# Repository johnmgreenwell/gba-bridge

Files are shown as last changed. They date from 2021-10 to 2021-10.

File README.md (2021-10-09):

# GBA Bridge Project

Gameboy Advance cartridge data read/write to/from SD card

## Overview

This AVR ATMega325 microcontroller-based project is capable of extracting ROM and RAM from Gameboy Advance (GBA) cartridges and saving them to an SD card. It is also capable of uploading RAM to a gameboy cartridge from a file on the SD card, allowing transfer of save data from one cartridge to another. Supported RAM types include EEPROM, Flash, FRAM, and SRAM of varying memory sizes.

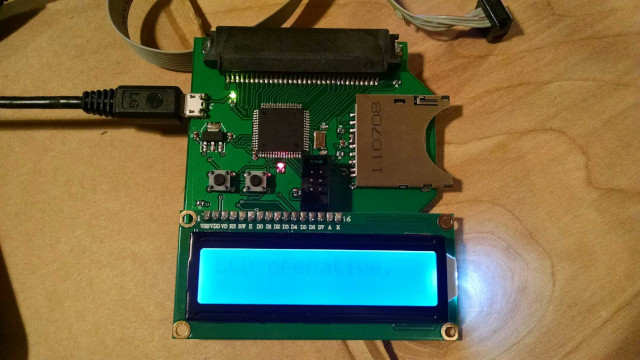
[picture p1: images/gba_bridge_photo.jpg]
Final Build


An simple LCD provides feedback to the user concerning mode and operation, controlled with two simple pushbuttons. The USB micro connection provides power, but does not transmit data. Improvements to this design might omit the SD card and physical UI, and implement the read/write feature entirely by way of USB connection.

Some reverse-engineering of transmission protocol was necessary to successfully communicate with GBA cartridge 8-pin EEPROM chips. This was made possible by tying each pin to a digital oscilloscope while the game was active, and triggering on save/load commands issued within the game.

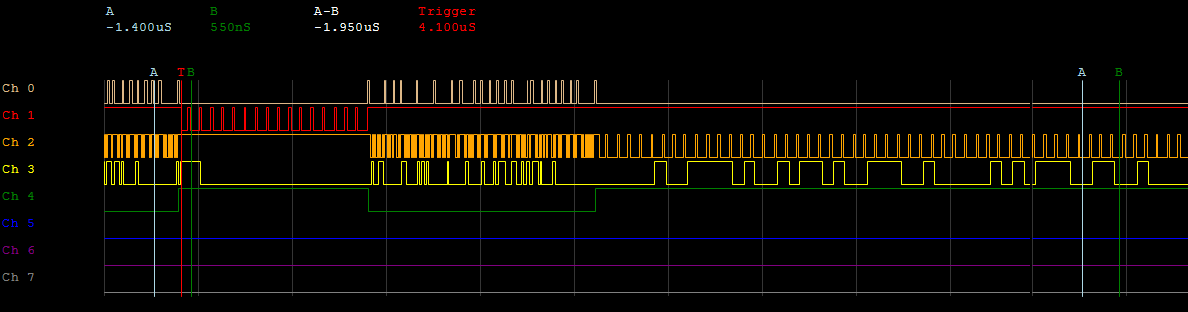
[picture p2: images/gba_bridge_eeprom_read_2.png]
EEPROM Read Example


In the current version, the user must examine the game cartridge internal circuit board to ascertain the type of memory used. Improvements to the code might add functionality which auto-detects RAM type and read/writes as desired.

Data extracted from the GBA cartridge is available as a .sav file on the SD card. To upload a .sav file to the RAM on a GBA cartridge, a file called up.sav containing the data should be placed on the SD card and then the appropriate steps followed in the UI of the board.

## Code

The main project file gba_bridge.c depends on separate header and source files to control peripheral devices, including the GBA cartridge. The collective C code was written and compiled in AVR Visual Studio 6, and the resulting .hex file uploaded to the board using *avrdude* through ICSP. 

The code consists of an extended state machine as a function of user input through the two onboard pushbuttons.

```c
	/* Continual Loop */
	/* This state machine cycles through options indicated */
	/* by user input about course of computation action.   */
	/* State machine states:			*/
	/* 0: Introductory screen			*/
	/* 1: Read from ROM select			*/
	/* 2: Read RAM select EEPROM 8k		*/
	/* 3: Read ROM select 2MB			*/
	/* 4: Read RAM select EEPROM 512	*/
	/* 5: Write RAM select okay			*/
	/* 6: Read ROM select 4MB			*/
	/* 7: Read ROM select 8MB			*/
	/* 8: Read ROM select 16MB			*/
	/* 9: Read ROM select 32MB			*/
	/* 10: Execute Read ROM 2MB			*/
	/* 11: Execute Read ROM 4MB			*/
	/* 12: Execute Read ROM 8MB			*/
	/* 13: Execute Read ROM 16MB		*/
	/* 14: Execute Read ROM 32MB		*/
	/* 15: Read RAM select Flash		*/
	/* 16: Read RAM select F/SRAM		*/
	/* 17: Execute RAM read EEPROM 8k	*/
	/* 18: Execute RAM read	EEPROM 512	*/
	/* 19: Execute RAM write EEPROM 512	*/
	/* 20: Execute RAM read Flash		*/
	/* 21: Execute RAM read F/SRAM		*/
	/* 22: Execute RAM write EEPROM 8k	*/
	/* 23: Execute RAM write Flash		*/
	/* 24: Execute RAM write F/SRAM		*/
	/* 25: Write RAM select EEPROM 512	*/
	/* 26: Write RAM select EEPROM 8k	*/
	/* 27: Write RAM select Flash		*/
	/* 28: Write RAM select F/SRAM		*/
```

## Schematic

The schematic and PCB CAD files as developed in KiCad provide the required components and connections of the design. It may be necessary to compatibility update the older files to newer KiCad format.

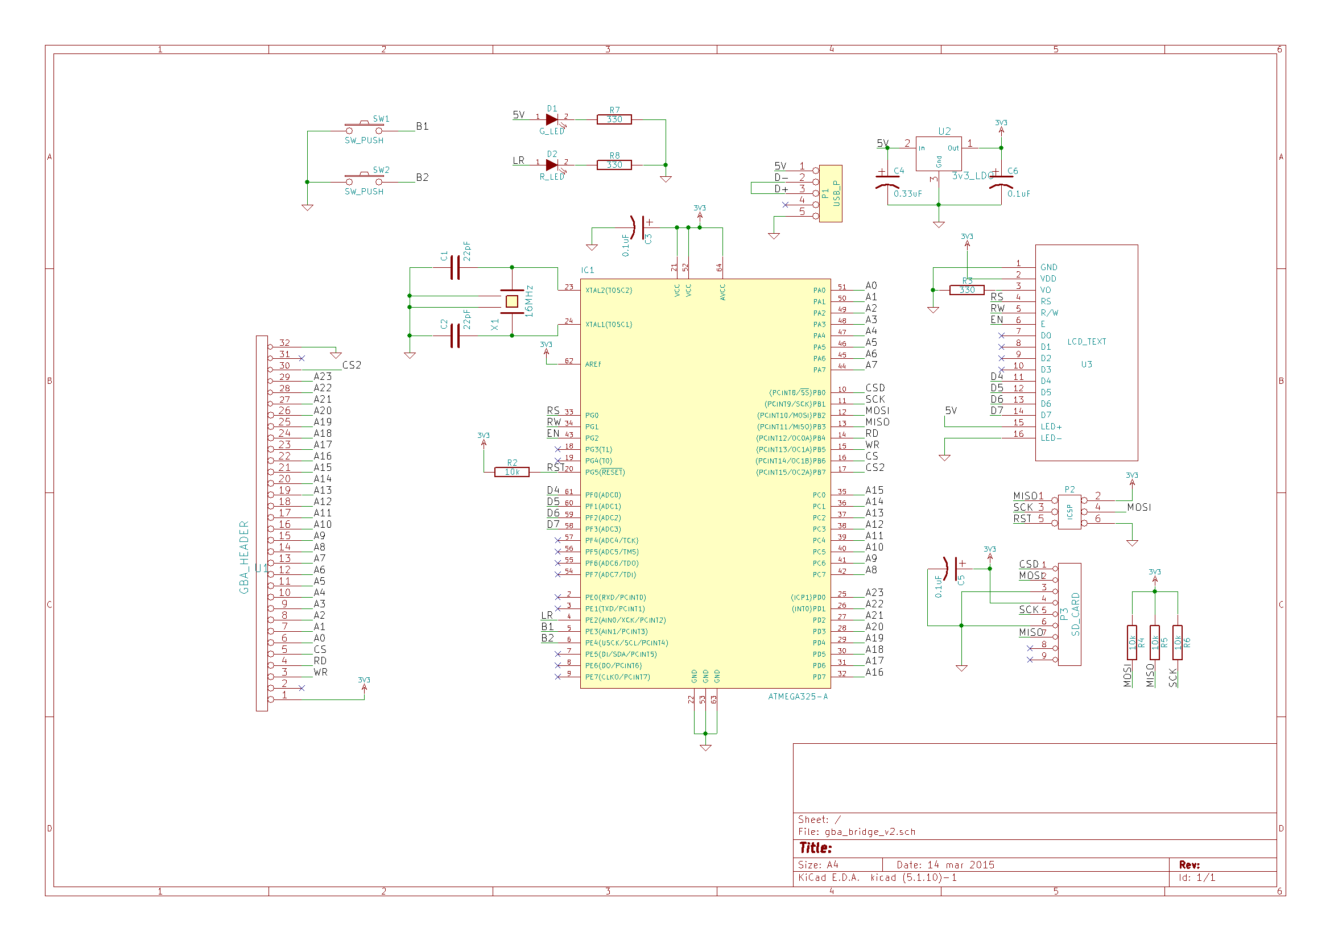
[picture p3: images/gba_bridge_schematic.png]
Schematic


Gerber files generated from the PCB layout in KiCad are also available.

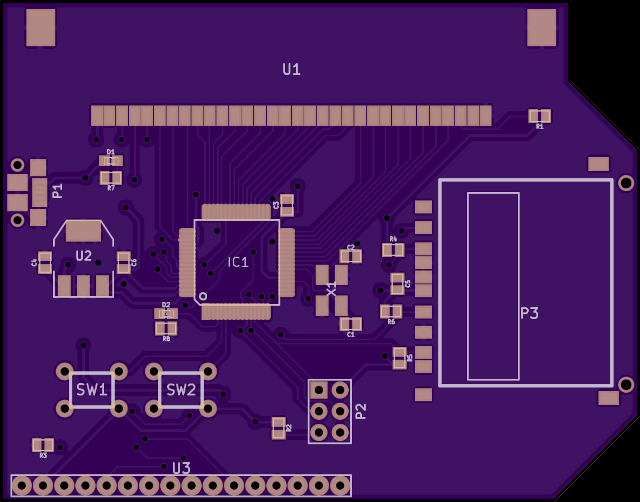
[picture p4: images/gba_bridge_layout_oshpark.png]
PCB Layout


## License

MIT © 2014 John Greenwell

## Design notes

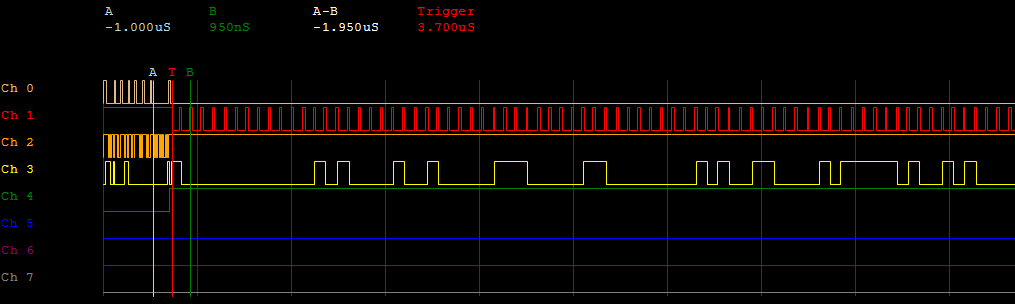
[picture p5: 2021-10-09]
images/gba_bridge_eeprom_write.png

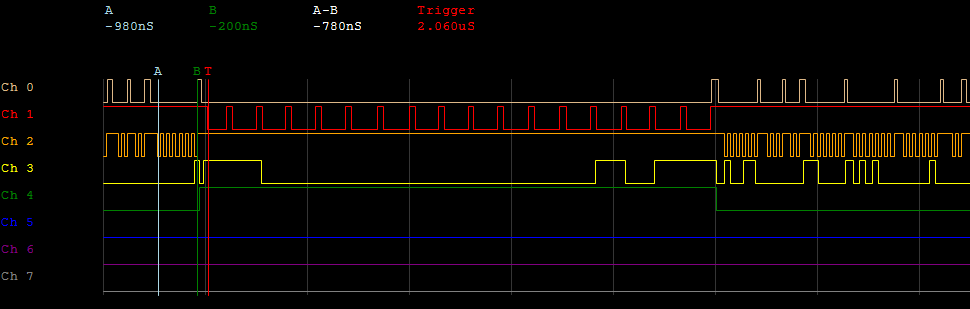
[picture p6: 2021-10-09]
images/gba_bridge_eeprom_read.png

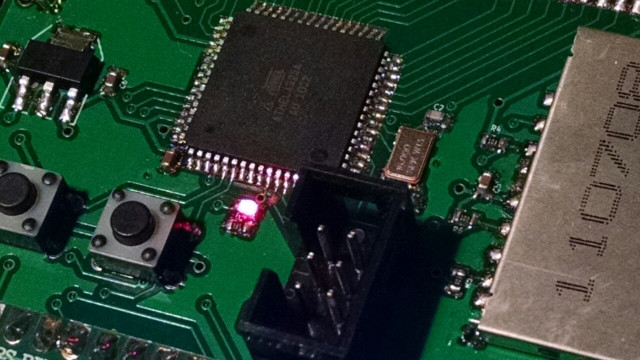
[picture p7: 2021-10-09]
images/gba_bridge_photo_closeup.jpg

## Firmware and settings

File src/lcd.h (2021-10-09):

#ifndef LCD_H
#define LCD_H
/*************************************************************************
 Title	:   C include file for the HD44780U LCD library (lcd.c)
 Author:    Peter Fleury <pfleury@gmx.ch>  http://jump.to/fleury
 File:	    $Id: lcd.h,v 1.13.2.2 2006/01/30 19:51:33 peter Exp $
 Software:  AVR-GCC 3.3
 Hardware:  any AVR device, memory mapped mode only for AT90S4414/8515/Mega
***************************************************************************/

/**
 @defgroup pfleury_lcd LCD library
 @code #include <lcd.h> @endcode
 
 @brief Basic routines for interfacing a HD44780U-based text LCD display

 Originally based on Volker Oth's LCD library,
 changed lcd_init(), added additional constants for lcd_command(), 
 added 4-bit I/O mode, improved and optimized code.
       
 Library can be operated in memory mapped mode (LCD_IO_MODE=0) or in 
 4-bit IO port mode (LCD_IO_MODE=1). 8-bit IO port mode not supported.

 Memory mapped mode compatible with Kanda STK200, but supports also 
 generation of R/W signal through A8 address line.
       
 @author Peter Fleury pfleury@gmx.ch http://jump.to/fleury
 
 @see The chapter <a href="http://homepage.sunrise.ch/mysunrise/peterfleury/avr-lcd44780.html" target="_blank">Interfacing a HD44780 Based LCD to an AVR</a>
      on my home page.

 NOTE: This library was modified by John Greenwell for function expansion, 2014.

*/

/*@{*/

#if (__GNUC__ * 100 + __GNUC_MINOR__) < 303
#error "This library requires AVR-GCC 3.3 or later, update to newer AVR-GCC compiler !"
#endif

#include <inttypes.h>
#include <avr/pgmspace.h>

/** 
 *  @name  Definitions for MCU Clock Frequency
 *  Adapt the MCU clock frequency in Hz to your target. 
 */
#define XTAL 16000000UL		/**< clock frequency in Hz, used to calculate delay timer */


/**
 * @name  Definition for LCD controller type
 * Use 0 for HD44780 controller, change to 1 for displays with KS0073 controller.
 */
#define LCD_CONTROLLER_KS0073 0  /**< Use 0 for HD44780 controller, 1 for KS0073 controller */

/**
 * @name  Definition for LCD Wiring
 * Use LCD_IO_MODE 0 for memory mapped mode, 1 for default IO port mode.
 * Use LCD_ALP_MODE 1 only if all data line are on one port, from 3..0 in order
 * Use LCD_IOX_MODE 1 only if leveraging iox.h for GPIO expansion ICs, configure below
 * Use LCD_SHR_MODE 1 only if leveraging external shift register for LCD wiring, configure
 * Note that any special configuration mode is only possible if LCD_IO_MODE is enabled
 * Notes that multiple special modes enabled is meaningless; will be assigned by order
 * of priority in descending order as listed. 
 */
#define LCD_IO_MODE     1		/**< 0: memory mapped mode, 1: IO port mode */
#define LCD_ALP_MODE	1		/**< 0: IO port default, 1: Efficiency data all in port */
#define LCD_IOX_MODE	0		/**< 0: IO port default, 1: Leverage iox.h GPIO expand */
#define LCD_SHR_MODE	0		/**< 0: IO port default, 1: Leverage SPI shift reg */

/** 
 *  @name  Definitions for Display Size 
 *  Change these definitions to adapt setting to your display
 */
#define LCD_LINES           2	/**< number of visible lines of the display */
#define LCD_DISP_LENGTH    16	/**< visibles characters per line of the display */
#define LCD_LINE_LENGTH  0x40	/**< internal line length of the display    */

#define LCD_WRAP_LINES  0		/**< 0: no wrap, 1: wrap at end of visibile line */

#define LCD_START_LINE1  0x00	/**< DDRAM address of first char of line 1 */
#define LCD_START_LINE2  0x40	/**< DDRAM address of first char of line 2 */
#define LCD_START_LINE3  0x14	/**< DDRAM address of first char of line 3 */
#define LCD_START_LINE4  0x54	/**< DDRAM address of first char of line 4 */

#if LCD_IO_MODE
/**
 *  @name Definitions for 4-bit IO mode
 *  Change LCD_PORT if you want to use a different port for the LCD pins.
 *
 *  The four LCD data lines and the three control lines RS, RW, E can be on the 
 *  same port or on different ports. 
 *  Change LCD_RS_PORT, LCD_RW_PORT, LCD_E_PORT if you want the control lines on
 *  different ports. 
 *
 *  Normally the four data lines should be mapped to bit 0..3 on one port, but it
 *  is possible to connect these data lines in different order or even on different
 *  ports by adapting the LCD_DATAx_PORT and LCD_DATAx_PIN definitions.
 *  
 */
#define LCD_PORT		PORTF		/**< port for the LCD lines (if LCD_ALP_MODE) */
#define LCD_DDR			DDRF		/**< DDR for the LCD lines (if LCD_ALP_MODE) */

#define LCD_DATA0_PORT	PORTF		/**< port for 4bit data bit 0 */
#define LCD_DATA0_DDR	DDRF		/**< DDR for 4bit data bit 0 */
#define LCD_DATA0_PINR	PINF		/**< PIN reg for 4bit data bit 0 */	
#define LCD_DATA0_PIN	0			/**< pin for 4bit data bit 0  */

#define LCD_DATA1_PORT	PORTF		/**< port for 4bit data bit 1 */
#define LCD_DATA1_DDR	DDRF		/**< DDR for 4bit data bit 1 */
#define LCD_DATA1_PINR	PINF		/**< PIN reg for 4bit data bit 1 */
#define LCD_DATA1_PIN	1			/**< pin for 4bit data bit 1  */

#define LCD_DATA2_PORT	PORTF		/**< port for 4bit data bit 2 */
#define LCD_DATA2_DDR	DDRF		/**< DDR for 4bit data bit 2 */
#define LCD_DATA2_PINR	PINF		/**< PIN reg for 4bit data bit 2 */
#define LCD_DATA2_PIN	2			/**< pin for 4bit data bit 2  */

#define LCD_DATA3_PORT	PORTF		/**< port for 4bit data bit 3 */
#define LCD_DATA3_DDR	DDRF		/**< DDR for 4bit data bit 3 */
#define LCD_DATA3_PINR	PINF		/**< PIN reg for 4bit data bit 3 */
#define LCD_DATA3_PIN	3			/**< pin for 4bit data bit 3  */

#define LCD_RS_PORT		PORTG		/**< port for RS line         */
#define LCD_RS_DDR		DDRG		/**< DDR for RS line		  */
#define LCD_RS_PIN		0			/**< pin  for RS line         */

#define LCD_RW_PORT		PORTG		/**< port for RW line         */
#define LCD_RW_DDR		DDRG		/**< DDR for RW line		  */
#define LCD_RW_PIN		1			/**< pin  for RW line         */

#define LCD_E_PORT		PORTG		/**< port for Enable line     */
#define LCD_E_DDR		DDRG		/**< DDR for Enable line	  */
#define LCD_E_PIN		2			/**< pin  for Enable line     */


#elif defined(__AVR_AT90S4414__) || defined(__AVR_AT90S8515__) || defined(__AVR_ATmega64__) || \
      defined(__AVR_ATmega8515__)|| defined(__AVR_ATmega103__) || defined(__AVR_ATmega128__) || \
      defined(__AVR_ATmega161__) || defined(__AVR_ATmega162__)
/*
 *  memory mapped mode is only supported when the device has an external data memory interface
 */
#define LCD_IO_DATA      0xC000    /* A15=E=1, A14=RS=1                 */
#define LCD_IO_FUNCTION  0x8000    /* A15=E=1, A14=RS=0                 */
#define LCD_IO_READ      0x0100    /* A8 =R/W=1 (R/W: 1=Read, 0=Write   */
#else
#error "external data memory interface not available for this device, use 4-bit IO port mode"

#endif


/**
 *  @name Definitions for LCD command instructions
 *  The constants define the various LCD controller instructions which can be passed to the 
 *  function lcd_command(), see HD44780 data sheet for a complete description.
 */
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

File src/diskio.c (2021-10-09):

/*------------------------------------------------------------------------/
/  MMCv3/SDv1/SDv2 (in SPI mode) control module
/-------------------------------------------------------------------------/
/
/  Copyright (C) 2012, ChaN, all right reserved.
/
/ * This software is a free software and there is NO WARRANTY.
/ * No restriction on use. You can use, modify and redistribute it for
/   personal, non-profit or commercial products UNDER YOUR RESPONSIBILITY.
/ * Redistributions of source code must retain the above copyright notice.
/
/--------------------------------------------------------------------------/
/
/	Edited by John Greenwell for use with AVR, 05 March 2013.
/
/-------------------------------------------------------------------------*/


#include "diskio.h"		/* Common include file for FatFs and disk I/O layer */


/*-------------------------------------------------------------------------*/
/* Platform dependent macros and functions needed to be modified           */
/*-------------------------------------------------------------------------*/

#ifndef F_CPU
 #define F_CPU 16000000UL
#endif

#include <avr/io.h>				/* Include device specific declaration file here */
#include <util/delay.h>

/* Define 1 if SPI initialized prior to SD use */
#define SPI_ALREADY	0

#define	INIT_PORT()	init_port()	/* Initialize MMC control port */
#define DLY_US(n)	_delay_us(n)	/* Delay n microseconds */

#define SPI_PORT	PORTB
#define SPI_DDR		DDRB
#define SPI_MOSI	2
#define SPI_MISO	3
#define SPI_SCK		1
#define SPI_CS_PORT	PORTB
#define SPI_CS_DDR	DDRB
#define SPI_CS		0

/*---------------------------------------------------------*/
/* User Provided Timer Function for FatFs module           */
/*---------------------------------------------------------*/

DWORD get_fattime (void)
{
	return	  ((DWORD)(2012 - 1980) << 25)	/* Year = 2012 */
	| ((DWORD)1 << 21)				/* Month = 1 */
	| ((DWORD)1 << 16)				/* Day_m = 1*/
	| ((DWORD)0 << 11)				/* Hour = 0 */
	| ((DWORD)0 << 5)				/* Min = 0 */
	| ((DWORD)0 >> 1);				/* Sec = 0 */
}

/*---------------------------------------------------------*/
/* User Provided ff_wtoupper() for FatFs module           */
/*---------------------------------------------------------*/
WCHAR ff_wtoupper (WCHAR chr) {
	return chr;
}

/*---------------------------------------------------------*/
/* User Provided ff_convert() for FatFs module           */
/*---------------------------------------------------------*/
WCHAR ff_convert (WCHAR chr, UINT dir) {
	return chr;
}



/*--------------------------------------------------------------------------

   Module Private Functions

---------------------------------------------------------------------------*/

/* MMC/SD command (SPI mode) */
#define CMD0	(0)			/* GO_IDLE_STATE */
#define CMD1	(1)			/* SEND_OP_COND */
#define	ACMD41	(0x80+41)	/* SEND_OP_COND (SDC) */
#define CMD8	(8)			/* SEND_IF_COND */
#define CMD9	(9)			/* SEND_CSD */
#define CMD10	(10)		/* SEND_CID */
#define CMD12	(12)		/* STOP_TRANSMISSION */
#define CMD13	(13)		/* SEND_STATUS */
#define ACMD13	(0x80+13)	/* SD_STATUS (SDC) */
#define CMD16	(16)		/* SET_BLOCKLEN */
#define CMD17	(17)		/* READ_SINGLE_BLOCK */
#define CMD18	(18)		/* READ_MULTIPLE_BLOCK */
#define CMD23	(23)		/* SET_BLOCK_COUNT */
#define	ACMD23	(0x80+23)	/* SET_WR_BLK_ERASE_COUNT (SDC) */
#define CMD24	(24)		/* WRITE_BLOCK */
#define CMD25	(25)		/* WRITE_MULTIPLE_BLOCK */
#define CMD41	(41)		/* SEND_OP_COND (ACMD) */
#define CMD55	(55)		/* APP_CMD */
#define CMD58	(58)		/* READ_OCR */

/* Card type flags (CardType) */
#define CT_MMC		0x01		/* MMC ver 3 */
#define CT_SD1		0x02		/* SD ver 1 */
#define CT_SD2		0x04		/* SD ver 2 */
#define CT_SDC		0x06		/* SD */
#define CT_BLOCK	0x08		/* Block addressing */


static
DSTATUS Stat = STA_NOINIT;	/* Disk status */

static
BYTE CardType;			/* b0:MMC, b1:SDv1, b2:SDv2, b3:Block addressing */


/*-----------------------------------------------------------------------*/
/* Initialize the port                                                   */
/*-----------------------------------------------------------------------*/
void init_port() {
#if SPI_ALREADY==0
	// Set CS, MOSI, SCK as outputs, MISO as input
	SPI_DDR |= (1<<SPI_CS)|(1<<SPI_MOSI)|(1<<SPI_SCK);
	SPI_DDR &= ~(1<<SPI_MISO);

	// Enable SPI, Master, speed fosc/16
	SPCR = (1<<SPE)|(1<<MSTR)|(1<<SPR0);
	SPSR = (1<<SPI2X);
#endif

	// Initiate with CS high, deselected
	SPI_CS_DDR |= (1<<SPI_CS);
	SPI_CS_PORT |= (1<<SPI_CS);
}


/*-----------------------------------------------------------------------*/
/* Transmit bytes to the card (bitbanging)                               */
/*-----------------------------------------------------------------------*/

static
void xmit_mmc (
	const BYTE* buff,	/* Data to be sent */
	UINT bc				/* Number of bytes to send */
)
{
	BYTE d;

	do {
		d = *buff++;	/* Get a byte to be sent */
		SPDR = d;		/* Send byte via SPI */
		while(!(SPSR & (1<<SPIF)));	/* Wait until SPI transmit complete */
	} while (--bc);
}



/*-----------------------------------------------------------------------*/
/* Receive bytes from the card (bitbanging)                              */
/*-----------------------------------------------------------------------*/

static
void rcvr_mmc (
	BYTE *buff,	/* Pointer to read buffer */
	UINT bc		/* Number of bytes to receive */
)
{

	do {
	SPDR = 0xFF;	/* Send dummy byte */
	while(!(SPSR & (1<<SPIF)));	/* Wait until SPI transmit complete */
	*buff++ = SPDR;
	} while (--bc);
}



/*-----------------------------------------------------------------------*/
/* Wait for card ready                                                   */
/*-----------------------------------------------------------------------*/

static
int wait_ready (void)	/* 1:OK, 0:Timeout */
{
	BYTE d;
	UINT tmr;


	for (tmr = 5000; tmr; tmr--) {	/* Wait for ready in timeout of 500ms */
		rcvr_mmc(&d, 1);
		if (d == 0xFF) break;
		DLY_US(100);
	}

	return tmr ? 1 : 0;
}



/*-----------------------------------------------------------------------*/
/* Deselect the card and release SPI bus                                 */
/*-----------------------------------------------------------------------*/

static
void deselect (void)
{
	BYTE d;

	SPI_CS_PORT |= (1<<SPI_CS);	/* CS HIGH */
	rcvr_mmc(&d, 1);	/* Dummy clock (force DO hi-z for multiple slave SPI) */
}



/*-----------------------------------------------------------------------*/
/* Select the card and wait for ready                                    */
/*-----------------------------------------------------------------------*/

static
int select (void)	/* 1:OK, 0:Timeout */
{
	BYTE d;

	SPI_CS_PORT &= ~(1<<SPI_CS);	/* CS LOW */
	rcvr_mmc(&d, 1);	/* Dummy clock (force DO enabled) */

	if (wait_ready()) return 1;	/* OK */
	deselect();
	return 0;			/* Failed */
}
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
